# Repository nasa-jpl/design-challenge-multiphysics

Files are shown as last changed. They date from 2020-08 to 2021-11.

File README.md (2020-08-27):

Jet Propulsion Laboratory, California Institute of Technology (NASA JPL)
# Multiphysics optical instrument design problem: A JPL design challenge

As additive manufacturing has become more mainstream, academic and industrial
partners have reached out to JPL for "real world" design problems to better
explore this new design space. In response to these requests, a prototypical JPL
design problem is posed here as a design challenge to the public. The primary
intention here is to provide real world context for people to explore new design
methodologies in a framework that is comparable across investigators. The
challenge is thus open ended with no completion date or winners: think of this
more as a benchmark problem similar to the NASA Common Research Model used in
aerodynamics research.

# The design problem overview

This design problem corresponds to the design of a prototypical optical instrument
support bracket as illustrated below. Optical instrument structural design is often driven by two
load cases: spacecraft launch and extreme thermal conditions while in space.
The design problem is thus mutliphysics in nature, requiring a coupled
thermomechanical approach. See [the complete design problem
definition](https://github.com/nasa-jpl/design-challenge-multiphysics/releases/latest) for more details.

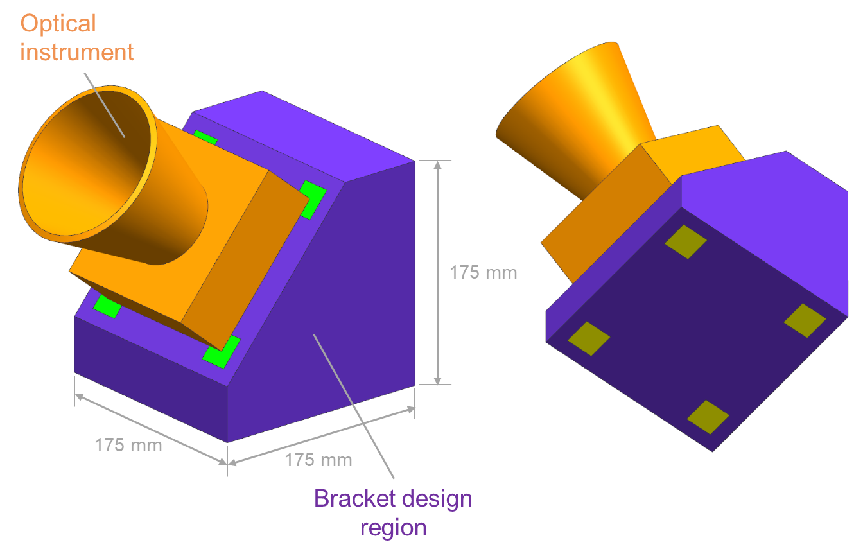
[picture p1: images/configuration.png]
Design problem geometric definition


# Solution submission process

Please submit your final designs using the [Github issue tracker](https://github.com/nasa-jpl/design-challenge-multiphysics/issues):
- Select "New Issue"
- Under the title, specify "(institution name):(lead submission author)". For 
  example, "Jet Propulsion Laboratory: Ryan Watkins". 
- Within the issue text, submit a summary of results and supporting materials as
 outlined in the second to last slide of [the complete design problem
definition](https://github.com/nasa-jpl/design-challenge-multiphysics/releases/latest).

# General notes

- Although originally inspired by additive manufacturing, designs need not be
restricted to just this manufacturing technique.
- Please cite this design problem as specified in the last slide of [the
  complete design problem
  definition](https://github.com/nasa-jpl/design-challenge-multiphysics/releases/latest).

© 2020 California Institute of Technology. Government sponsorship acknowledged.

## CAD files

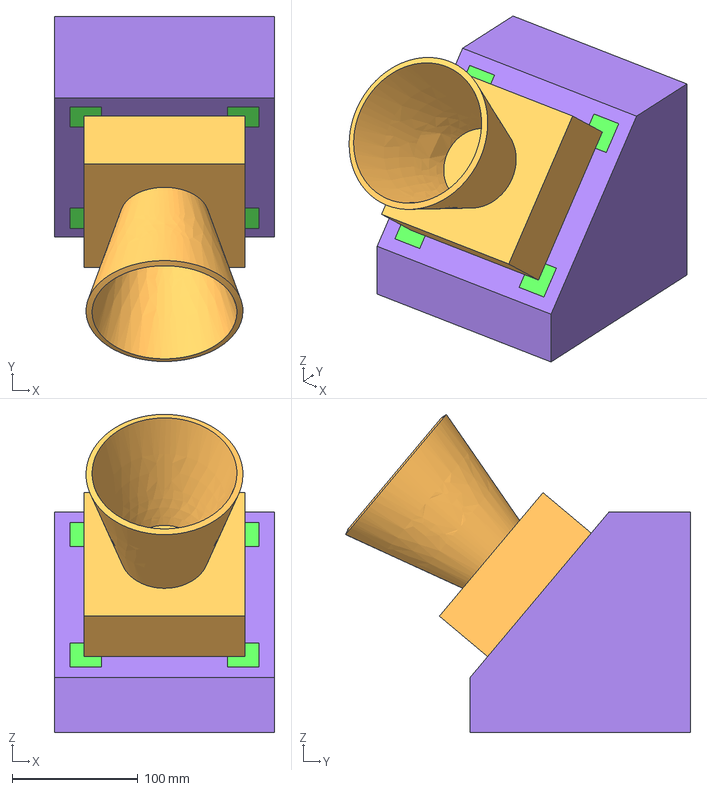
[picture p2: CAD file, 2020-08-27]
geometry.stp
175.0 x 273.9 x 252.7 mm

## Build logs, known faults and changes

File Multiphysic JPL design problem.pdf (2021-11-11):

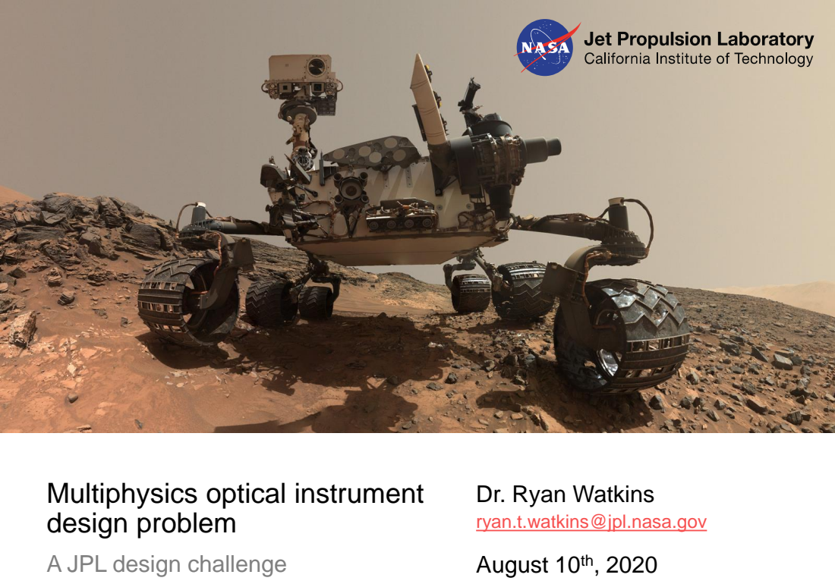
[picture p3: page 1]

Multiphysics optical instrument
design problem

Dr. Ryan Watkins
ryan.t.watkins@jpl.nasa.gov
August 10th, 2020

A JPL design challenge

## Optical instruments are one of the most common instruments flown by JPL and NASA

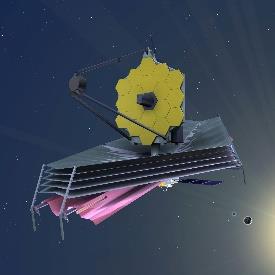
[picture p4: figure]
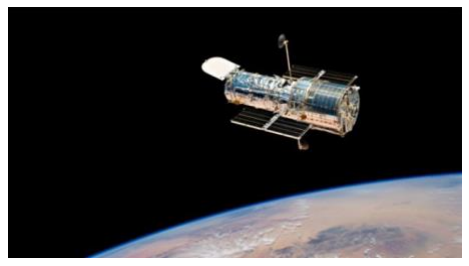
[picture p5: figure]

Telescopes
Ex: JWST, Hubble

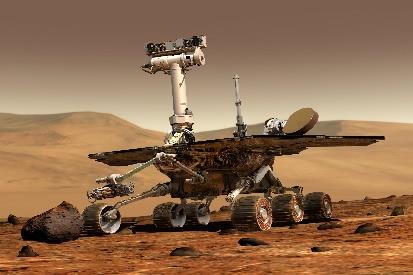
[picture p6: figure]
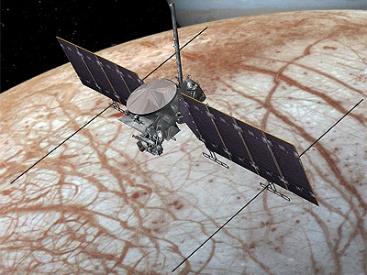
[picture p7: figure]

Spectrometers
Ex: Min-TES, MISE

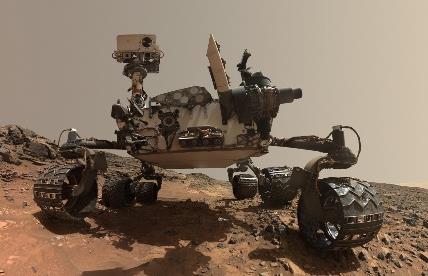
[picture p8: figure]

Operational instruments
Ex: star trackers, cameras

## To function properly, optical instruments have tight pointing requirements

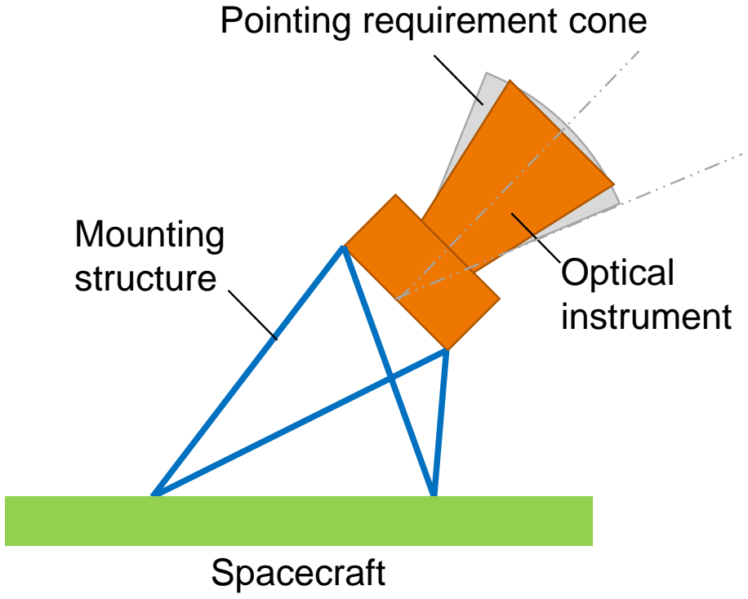
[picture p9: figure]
Spacecraft; Optical instrument; Mounting structure; Pointing requirement cone

## Pointing requirements are difficult to achieve due to extreme temperature conditions in space

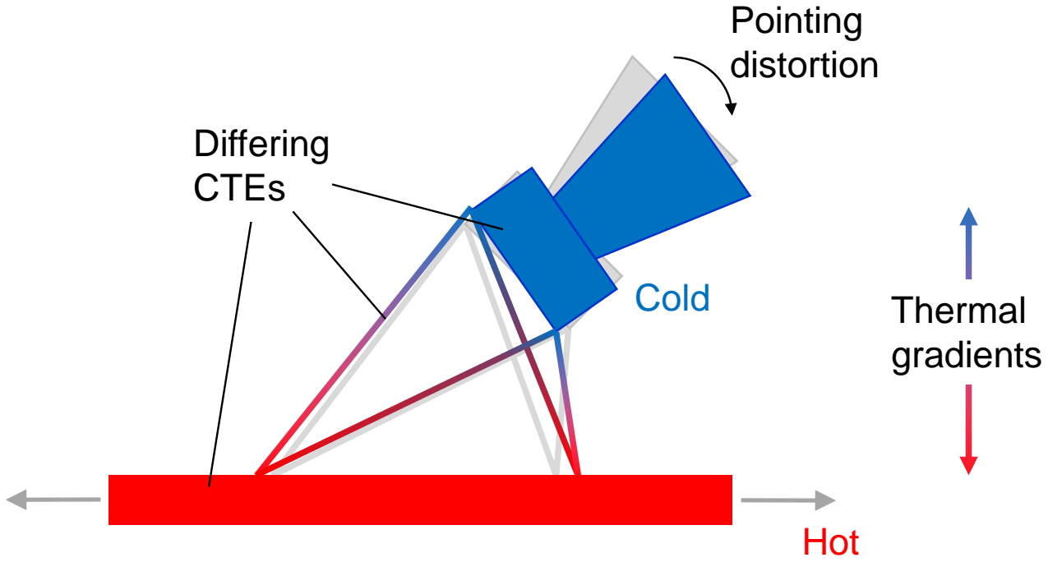
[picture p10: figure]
Hot; Cold; Pointing distortion; Differing CTEs; Thermal gradients

*CTE: Coefficient of Thermal Expansion

## Objective is to design the mounting structure for a prototypical star tracker

Mounting
structure | Star tracker

## Geometric definition and relevant components

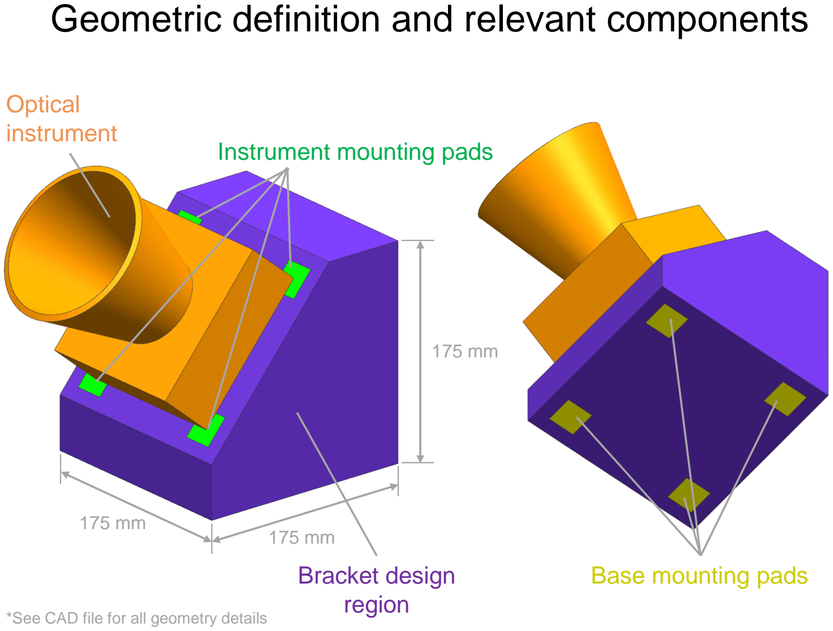
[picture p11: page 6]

Bracket design | Base mounting pads
region

Instrument mounting pads

Optical
instrument

*See CAD file for all geometry details

175 mm

175 mm

175 mm

## Design and non-design space

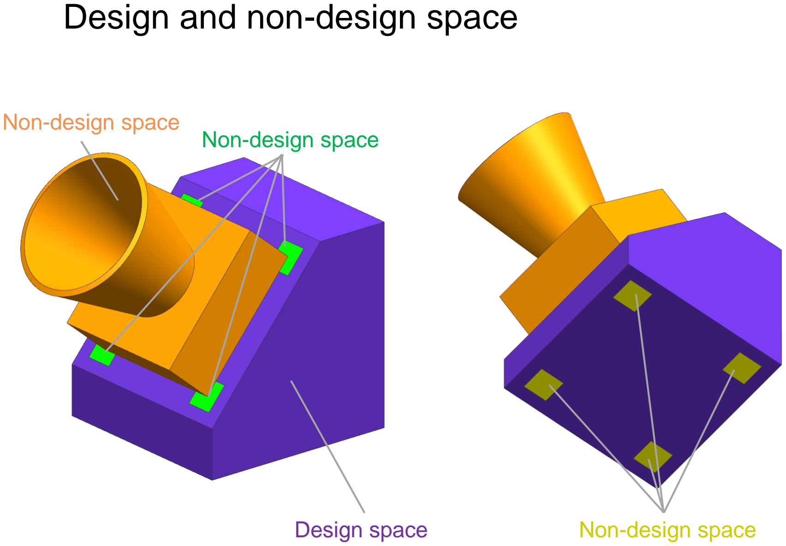
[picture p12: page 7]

Design space | Non-design space

Non-design space

Non-design space

## Materials

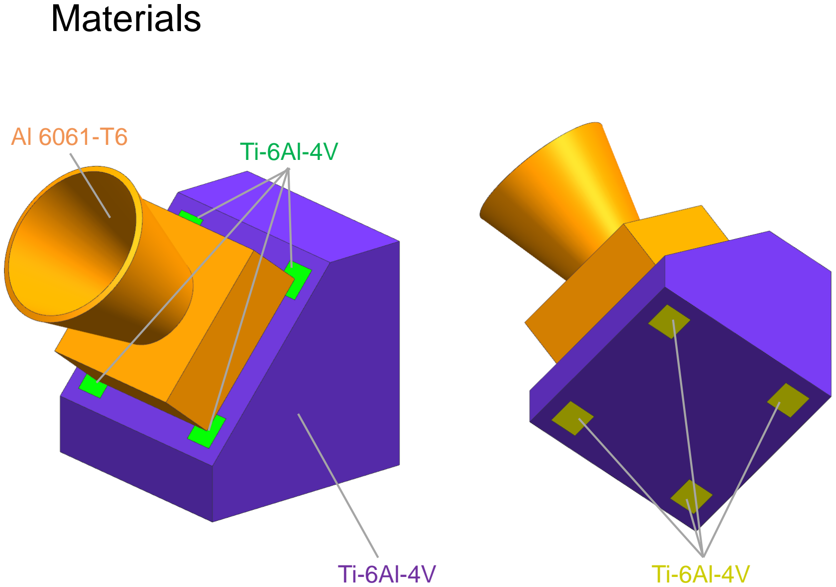
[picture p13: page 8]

Ti-6Al-4V | Ti-6Al-4V

Ti-6Al-4V Al 6061-T6

## Material properties

Ti 6Al-4V
- E = 110 GPa (16 Msi)
- ν = 0.31
- ρ = 4430 kg/m³
- α = 8.8 ppm/°C
- κ = 6.9 W/(m °C)
- σy = 827 MPa (120 ksi)
- σu = 896 MPa (130 ksi)

Al 6061-T6
- E = 68 GPa (9.9 MSi)
- ν = 0.33
- ρ = 9555* kg/m³
- α = 22.2 ppm/°C
- κ = 152.3 W/(m °C)

* This is not the true density of Al (which is 2700 kg/m³
). To achieve the appropriate instrument mass of 3 kg (without including concentrated masses), the material density has been scaled up.

## Relevant load cases

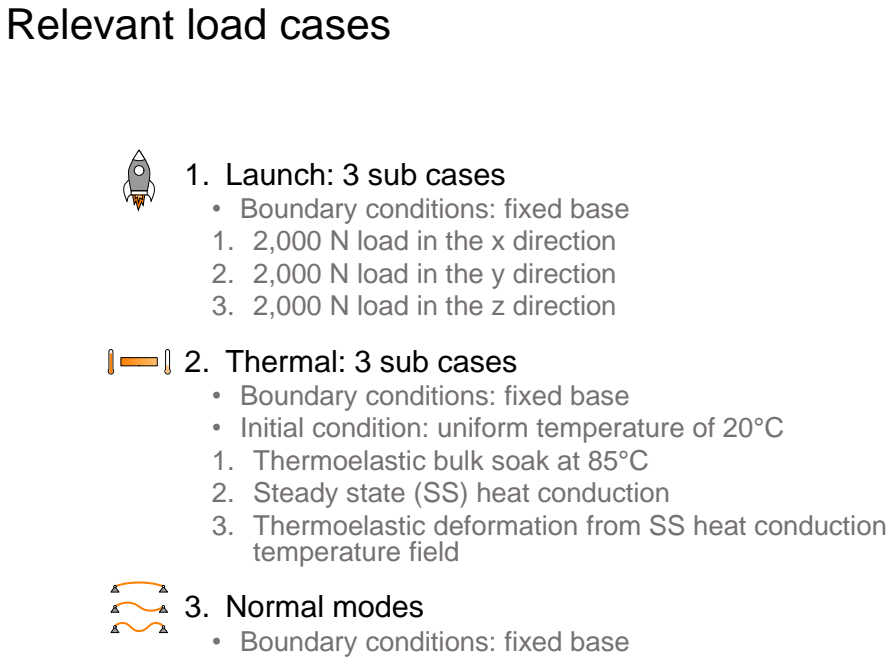
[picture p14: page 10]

1. Launch: 3 sub cases
• Boundary conditions: fixed base
1. 2,000 N load in the x direction
2. 2,000 N load in the y direction
3. 2,000 N load in the z direction
2. Thermal: 3 sub cases
• Initial condition: uniform temperature of 20°C
1. Thermoelastic bulk soak at 85°C
2. Steady state (SS) heat conduction
3. Thermoelastic deformation from SS heat conduction
temperature field
3. Normal modes

## Load case 1.1-1.3: launch

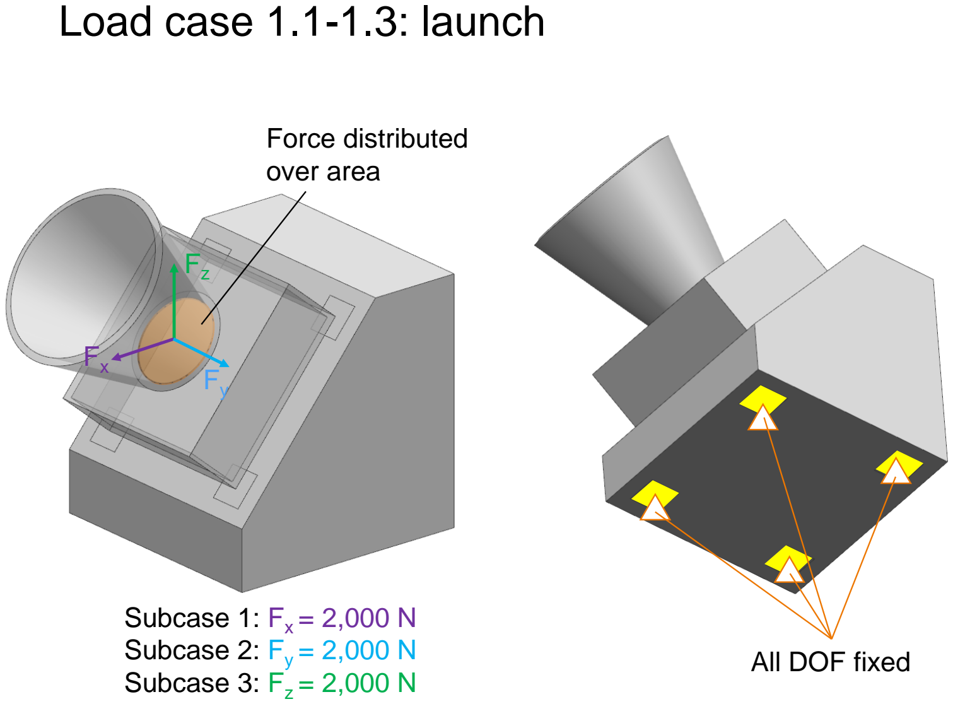
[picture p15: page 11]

Fx
Fy

Fz

Subcase 1: Fx = 2,000 N
Subcase 2: Fy = 2,000 N
Subcase 3: Fz = 2,000 N

All DOF fixed

Force distributed
over area

## Load case 2.1: bulk temperature soak

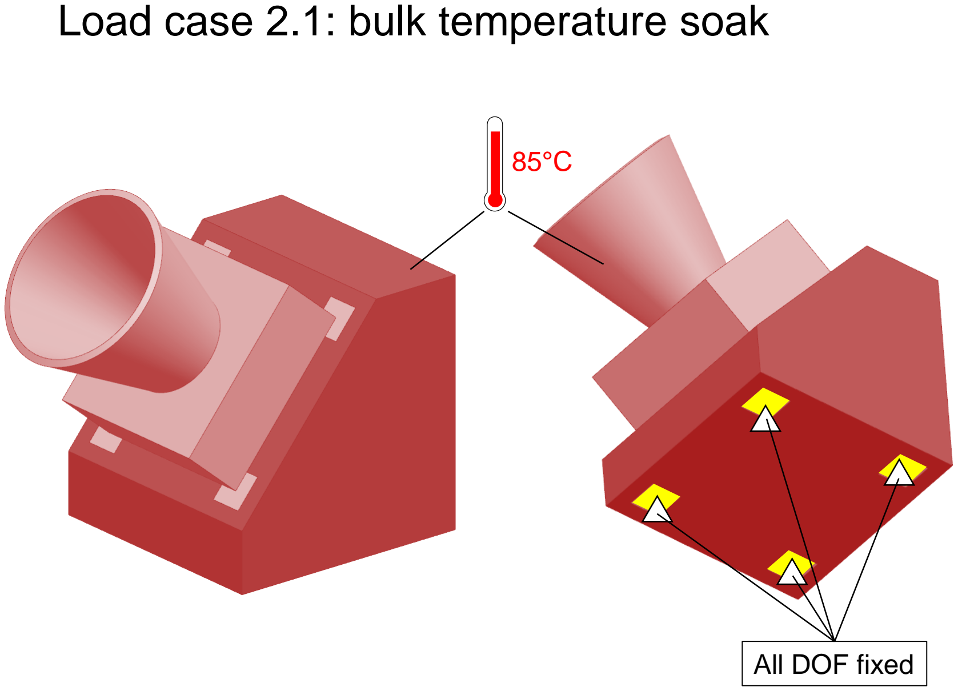
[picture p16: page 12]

85°C

All DOF fixed

## Load case 2.2: steady state heat conduction

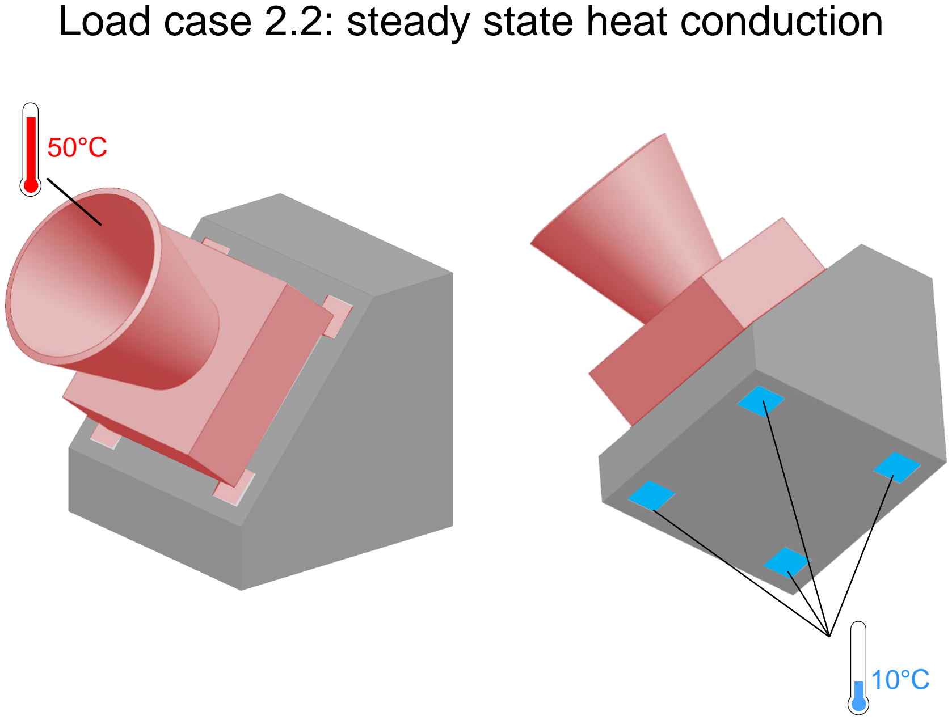
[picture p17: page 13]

10°C

50°C

## Load case 2.3: thermoelastic deformation from SS heat conduction temperature field

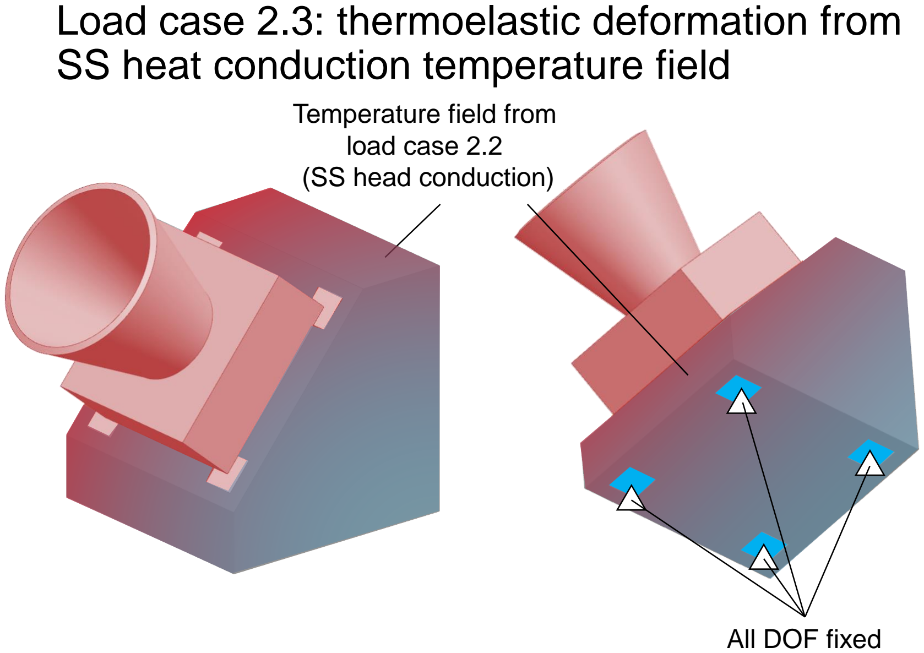
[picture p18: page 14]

All DOF fixed

Temperature field from
load case 2.2
(SS head conduction)

## Load case 3: normal modes

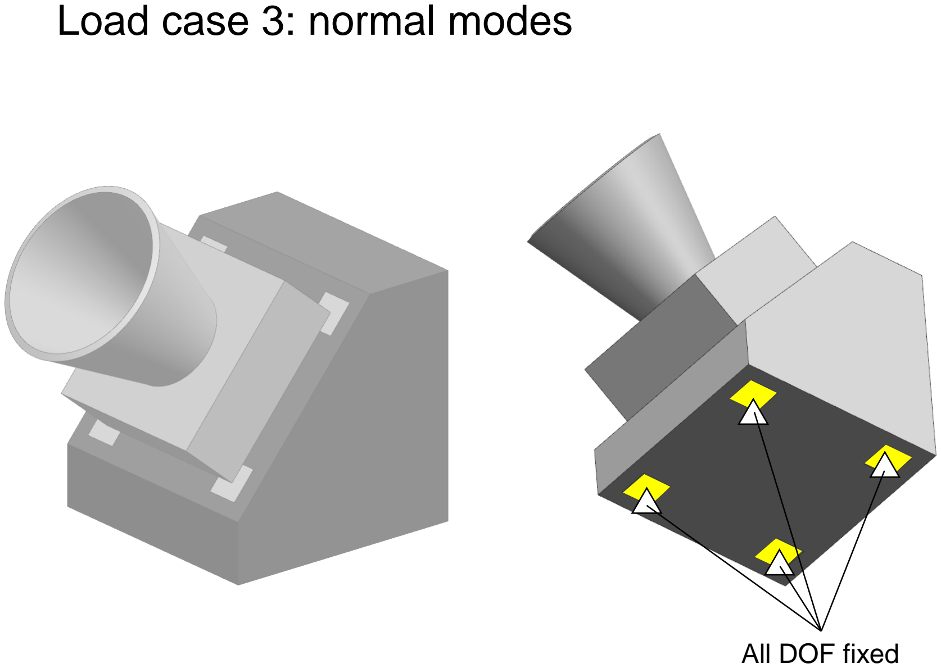
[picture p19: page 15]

All DOF fixed

## Design problem goal and requirements

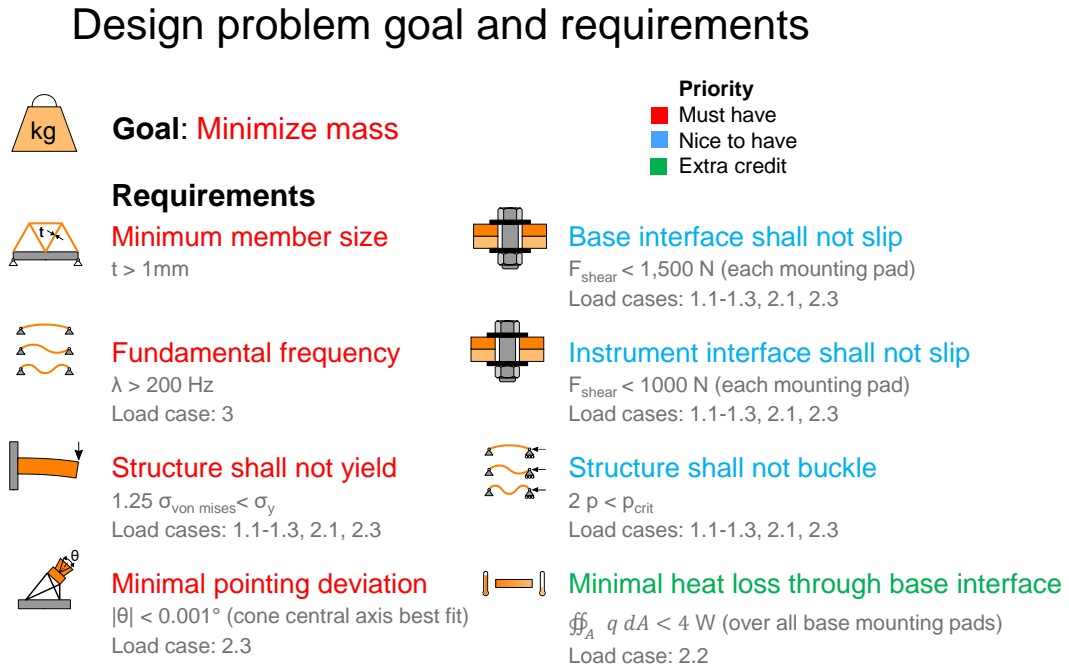
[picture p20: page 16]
Minimum member size; Fundamental frequency; λ > 200 Hz Load case: 3; Requirements

Priority
Must have
Nice to have
Extra credit

Goal: Minimize mass

Base interface shall not slip
Fshear < 1,500 N (each mounting pad)
Load cases: 1.1-1.3, 2.1, 2.3

Instrument interface shall not slip
Fshear < 1000 N (each mounting pad)

Structure shall not yield

Structure shall not buckle
2 p < pcrit

1.25 σvon mises< σy

Minimal pointing deviation
θ| < 0.001° (cone central axis best fit)
Load case: 2.3

Minimal heat loss through base interface

q dA < 4 W (over all base mounting pads)
Load case: 2.2

## Communication of results

1. Bracket mass (excluding mounting pads)
2. Requirements compliance
3. Geometry file of design (CAD, STL, etc)
4. Basic manufacturing plan
5. List of relevant modeling assumption

## Final notes

There are no stipulations on design methodology Ex: Topology optimization can be used but isn’t required

Design should be manufacturable
Manufacturing method is up to the designer

Cite problem definition as follows

Author: Ryan Watkins
Contact: ryan.t.watkins@jpl.nasa.gov Title: Multiphysics optical instrument design problem: A JPL design challenge

Institution: Jet Propulsion Laboratory Date: August 2020

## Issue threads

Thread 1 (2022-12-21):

University of Tulsa: Tovar, Murcek, Upton, Ward, and Rendon

watkinrt, 2022-12-21:
# Contributors
Andres Tovar, Eric Murcek, Hazel Upton, Mish Ward, Nathan Rendon

# Requirements check
Note: requirements were independently checked and may differ from the provided report.

Fundamental Frequency
        ❌ Min frequency: 113.0 Hz (ref > 200 Hz)
Max Stress
        ✅ LaunchX (Case 1.1): 481.5 MPa (ref < 661.6 MPa)
        ❌ LaunchY (Case 1.2): 1135 MPa (ref < 661.6 MPa)
        ✅ LaunchZ (Case 1.3): 377.2 MPa (ref < 661.6 MPa)
        ✅ Bulk Soak (Case 2.1): 349.2 MPa (ref < 661.6 MPa)
        ✅ ThermoElastic (Case 2.3): 68.4 MPa (ref < 661.6 MPa)
Minimum pointing deviation
        ✅ Pointing X: 0.0005990717790383983 deg (ref < 0.001 deg)
        ✅ Pointing Y: 3.340384052658358e-05 deg (ref < 0.001 deg)
Bolt slip
        LaunchX (Case 1.1)
                ✅ Instrument bolt shear forces: 168.6 N (ref < 1000 N)
                ✅ Instrument bolt shear forces: 167.8 N (ref < 1000 N)
                ❌ Instrument bolt shear forces 1183.3 N (ref < 1000 N)
                ❌ Instrument bolt shear forces: 1200.6 N (ref < 1000 N)
                ✅ Base bolt shear forces EID 1059588: 67.9 N (ref < 1500 N)
                ✅ Base bolt shear forces EID 1059589: 84.8 N (ref < 1500 N)
                ✅ Base bolt shear forces EID 1059590: 1068.6 N (ref < 1500 N)
                ✅ Base bolt shear forces EID 1059591: 860.6 N (ref < 1500 N)
        LaunchY (Case 1.2)
                ✅ Instrument bolt shear forces EID 1059584: 578.9 N (ref < 1000 N)
                ✅ Instrument bolt shear forces EID 1059585: 562.7 N (ref < 1000 N)
                ✅ Instrument bolt shear forces EID 1059586: 70.9 N (ref < 1000 N)
                ✅ Instrument bolt shear forces EID 1059587: 79.0 N (ref < 1000 N)
                ✅ Base bolt shear forces EID 1059588: 805.4 N (ref < 1500 N)
                ✅ Base bolt shear forces EID 1059589: 759.4 N (ref < 1500 N)
                ✅ Base bolt shear forces EID 1059590: 259.8 N (ref < 1500 N)
                ✅ Base bolt shear forces EID 1059591: 212.3 N (ref < 1500 N)
        LaunchZ (Case 1.3)
                ✅ Instrument bolt shear forces EID 1059584: 201.6 N (ref < 1000 N)
                ✅ Instrument bolt shear forces EID 1059585: 194.0 N (ref < 1000 N)
                ✅ Instrument bolt shear forces EID 1059586: 567.0 N (ref < 1000 N)
                ✅ Instrument bolt shear forces EID 1059587: 569.7 N (ref < 1000 N)
                ✅ Base bolt shear forces EID 1059588: 72.3 N (ref < 1500 N)
                ✅ Base bolt shear forces EID 1059589: 56.7 N (ref < 1500 N)
                ✅ Base bolt shear forces EID 1059590: 80.5 N (ref < 1500 N)
                ✅ Base bolt shear forces EID 1059591: 97.3 N (ref < 1500 N)
        BulkSoak (Case 2.1)
                ✅ Instrument bolt shear forces EID 1059584: 66.6 N (ref < 1000 N)
                ✅ Instrument bolt shear forces EID 1059585: 69.6 N (ref < 1000 N)
                ✅ Instrument bolt shear forces EID 1059586: 79.7 N (ref < 1000 N)
                ✅ Instrument bolt shear forces EID 1059587: 79.8 N (ref < 1000 N)
                ✅ Base bolt shear forces EID 1059588: 19.4 N (ref < 1500 N)
                ✅ Base bolt shear forces EID 1059589: 22.3 N (ref < 1500 N)
                ✅ Base bolt shear forces EID 1059590: 33.3 N (ref < 1500 N)
                ✅ Base bolt shear forces EID 1059591: 29.0 N (ref < 1500 N)
        ThermoElastic (Case 2.3)
                ✅ Instrument bolt shear forces EID 1059584: 34.7 N (ref < 1000 N)
                ✅ Instrument bolt shear forces EID 1059585: 34.6 N (ref < 1000 N)
                ✅ Instrument bolt shear forces EID 1059586: 71.9 N (ref < 1000 N)
                ✅ Instrument bolt shear forces EID 1059587: 71.9 N (ref < 1000 N)
                ✅ Base bolt shear forces EID 1059588: 6.7 N (ref < 1500 N)
                ✅ Base bolt shear forces EID 1059589: 6.8 N (ref < 1500 N)
                ✅ Base bolt shear forces EID 1059590: 59.6 N (ref < 1500 N)
                ✅ Base bolt shear forces EID 1059591: 59.6 N (ref < 1500 N)
Heat loss through base interface
        ✅ Heat flux: 0.41 W (ref < 4 W)

# Report

[Report](https://github.com/nasa-jpl/design-challenge-multiphysics/files/10280609/Rendon.Nathan.-.JPL.Final.Submission.pdf)
[Geometry](https://github.com/nasa-jpl/design-challenge-multiphysics/files/10280680/Final.Geometry.step.txt)

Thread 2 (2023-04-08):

Carnegie Mellon University: Sebastian Vargas

sebvar87, 2023-04-08:
Provided geometry. Will include report soon.
[Geometry SV.zip](https://github.com/nasa-jpl/design-challenge-multiphysics/files/11183512/Geometry.SV.zip)

watkinrt, 2023-07-13:
# Contributors
Sebastian Vargas

# Design

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

# Requirements check

*Note: requirements were independently checked and may differ from the provided report.*

### Mass
 - **Full system mass**: 4.17403 kg
 - **Bracket only** (excluding mounting pads): 0.9140300000000003 kg
### Minimum pointing deviation
 - ✅ **Pointing X**: 0.00013337884512850434 deg (ref < 0.001 deg)
  - ✅ **Pointing Y**: 2.2645612542640414e-05 deg (ref < 0.001 deg)
### Max stress
 - ✅ **LaunchX**: 131.5 (ref < 661.6 MPa)
 - ✅ **LaunchY**: 161.8 (ref < 661.6 MPa)
 - ✅ **LaunchZ**: 180.0 (ref < 661.6 MPa)
 - ✅ **BulkSoak**: 318.7 (ref < 661.6 MPa)
 - ✅ **ThermoElastic**: 133.4 (ref < 661.6 MPa)
### Bolt slip
 - **LaunchX**
                - ✅ **Instrument bolt shear forces EID 1059584**: 515.7 N (ref < 1000 N)
                - ✅ **Instrument bolt shear forces EID 1059585**: 515.8 N (ref < 1000 N)
                - ✅ **Instrument bolt shear forces EID 1059586**: 563.1 N (ref < 1000 N)
                - ✅ **Instrument bolt shear forces EID 1059587**: 571.6 N (ref < 1000 N)
                - ✅ **Base bolt shear forces EID 1059588**: 952.5 N (ref < 1500 N)
                - ✅ **Base bolt shear forces EID 1059589**: 943.3 N (ref < 1500 N)
                - ✅ **Base bolt shear forces EID 1059590**: 572.8 N (ref < 1500 N)
                - ✅ **Base bolt shear forces EID 1059591**: 571.9 N (ref < 1500 N)
 - **LaunchY**
                - ✅ **Instrument bolt shear forces EID 1059584**: 110.6 N (ref < 1000 N)
                - ✅ **Instrument bolt shear forces EID 1059585**: 111.0 N (ref < 1000 N)
                - ✅ **Instrument bolt shear forces EID 1059586**: 929.1 N (ref < 1000 N)
                - ✅ **Instrument bolt shear forces EID 1059587**: 929.2 N (ref < 1000 N)
                - ✅ **Base bolt shear forces EID 1059588**: 591.7 N (ref < 1500 N)
                - ✅ **Base bolt shear forces EID 1059589**: 598.6 N (ref < 1500 N)
                - ✅ **Base bolt shear forces EID 1059590**: 860.7 N (ref < 1500 N)
                - ✅ **Base bolt shear forces EID 1059591**: 867.5 N (ref < 1500 N)
 - **LaunchZ**
                - ✅ **Instrument bolt shear forces EID 1059584**: 287.2 N (ref < 1000 N)
                - ✅ **Instrument bolt shear forces EID 1059585**: 289.3 N (ref < 1000 N)
                - ✅ **Instrument bolt shear forces EID 1059586**: 989.0 N (ref < 1000 N)
                - ✅ **Instrument bolt shear forces EID 1059587**: 987.9 N (ref < 1000 N)
                - ✅ **Base bolt shear forces EID 1059588**: 116.7 N (ref < 1500 N)
                - ✅ **Base bolt shear forces EID 1059589**: 102.9 N (ref < 1500 N)
                - ✅ **Base bolt shear forces EID 1059590**: 934.1 N (ref < 1500 N)
                - ✅ **Base bolt shear forces EID 1059591**: 933.3 N (ref < 1500 N)
 - **BulkSoak**
                - ❌ **Instrument bolt shear forces EID 1059584**: 1812.1 N (ref < 1000 N)
                - ❌ **Instrument bolt shear forces EID 1059585**: 1783.6 N (ref < 1000 N)
                - ❌ **Instrument bolt shear forces EID 1059586**: 2225.4 N (ref < 1000 N)
                - ❌ **Instrument bolt shear forces EID 1059587**: 2256.9 N (ref < 1000 N)
                - ✅ **Base bolt shear forces EID 1059588**: 652.3 N (ref < 1500 N)
                - ✅ **Base bolt shear forces EID 1059589**: 688.4 N (ref < 1500 N)
                - ❌ **Base bolt shear forces EID 1059590**: 2282.3 N (ref < 1500 N)
                - ❌ **Base bolt shear forces EID 1059591**: 2298.5 N (ref < 1500 N)
 - **ThermoElastic**
                - ❌ **Instrument bolt shear forces EID 1059584**: 1094.8 N (ref < 1000 N)
                - ❌ **Instrument bolt shear forces EID 1059585**: 1093.1 N (ref < 1000 N)
                - ❌ **Instrument bolt shear forces EID 1059586**: 1273.7 N (ref < 1000 N)
                - ❌ **Instrument bolt shear forces EID 1059587**: 1272.3 N (ref < 1000 N)
                - ✅ **Base bolt shear forces EID 1059588**: 290.7 N (ref < 1500 N)
                - ✅ **Base bolt shear forces EID 1059589**: 290.0 N (ref < 1500 N)
                - ✅ **Base bolt shear forces EID 1059590**: 179.3 N (ref < 1500 N)
                - ✅ **Base bolt shear forces EID 1059591**: 181.3 N (ref < 1500 N)
### Heat loss through base interface
 - ✅  **Heat flux**: 0.24 W (ref < 4 W)
